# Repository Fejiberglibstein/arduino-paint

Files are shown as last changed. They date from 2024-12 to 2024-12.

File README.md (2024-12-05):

<div align="center">
    <h1>Arduino Paint</h1>
</div>

---

# Project setup

### Buy these

- [Arduino `x1`](https://store-usa.arduino.cc/products/arduino-uno-rev3?gad_source=1)
- [Proximity Sensors `x8`](https://www.adafruit.com/product/4019)
- [LED screen `x1`](https://www.adafruit.com/product/2601?gad_source=1)
- [Matrix Shield `x1`](https://www.adafruit.com/product/2601?gad_source=1)
- [Breadboard `x2`](https://www.adafruit.com/product/239)
- [Male-Female Jumper Wires `x1`](https://store-usa.arduino.cc/products/40-colored-male-female-jumper-wires)
- [Male-Male Jumper Wires `x1`](https://store-usa.arduino.cc/products/40-colored-male-male-jumper-wires)

### Printing
- Print everything found in `models/`
  
  - sensor_frame.stl `x8` (When slicing, orient so the front face is down)
  - back_bracket.stl `x8`
  - lego_base1.stl `x2` (Oriented so the lego fitting faces outwards)
  - lego_base2.stl `x2` (Oriented so the lego fitting faces outwards)

### Constructing the frame
- Construct a lego frame 48x24 studs, (41.2 x 20.6 cm)
  - Add a bridge extending width-wise across the middle to support the platform

- Place a 17.8 x 8.9 cm rectangle oriented vertically in the center of the lego
  frame (see picture below if you're confused)

### Wiring

- Place a sensor in each sensor frame and slot a bracket into the groove at the
  top of the bracket
  - Take each sensor frame and put 2 inside of each sensor base so the pins are face up
    (`./models/lego_base1.stl` and `./models/lego_base2.stl`)
  - Each sensor base will go on the lego frame  (refer to the picture below for details)
    - Each should be 4 studs diagonally backwards from each corner
    - Ensure the mount is angled towards the opposite corner of the frame

- You must wire the proximity sensors all together on 2 breadboards.
    - The breadboards should be placed on opposite ends of the frame
    - Connect 5 volts and GND to the +/- rails
    - The trigger and echo pins of each sensor will be connected to the same
      rail on the breadboard
    - You can follow the diagram found in `./documentation/circuit_design.pdf`

- The matrix shield pins must be soldered before use
    - Either solder wires to the pins to be used for trigger/echo or connect a jumper wire
      to the base of the pin
      
- Insert the pins on the matrix shield into the Arduino pin holes and
  connect the LED matrix to the shield
- Connect all wires on the Arduino to the circuit made on the breadboards, ensuring each sensor gets the correct pin

> <details>
>  <summary><b><code>  SPOILER  </code> Picture of setup</b></summary>
>
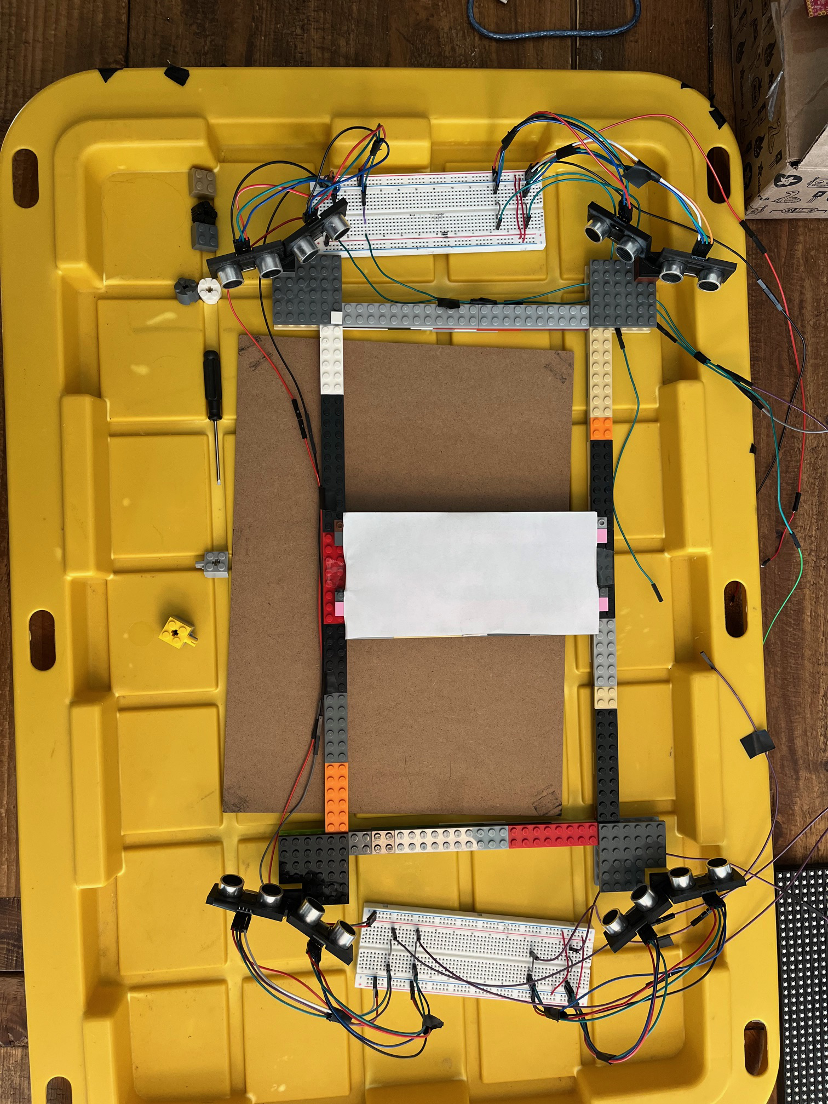
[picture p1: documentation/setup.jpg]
setup image
>  
> </details>

# Using and interacting with the project

### Compiling & Uploading

- Plug the arduino into a computer and compile and upload the sketch by simply
  running `make`, assuming you are on mac/linux and have arduino-cli installed.
    - Prior to this step, disconnect the sensors on pins 0 and 1. Once the sketch is uploaded, connect the wires again

> [!WARNING] 
> ### Using the arduino IDE
> If you are on windows and/or using the Arduino IDE, follow these steps:
> - In the arduino IDE, copy all the `.h` files and their respective `.cpp` files into
>   the arduino library folder into a folder called `math_lib/`.
> - In `arduino-paint.ino`, change the first #include line to the following
> ```diff
> - #include "point_translation.h"
> + #include <point_translation.h>
> ```

- Once it is on, you will be able to trace on the central rectangle and see the
  same trace appear on the LED screen.

- Press the `reset` button on the arduino to clear the screen

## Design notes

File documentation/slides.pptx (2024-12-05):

## Arduino Paint

Austin Thein & Katie Corra

## Project Description

There is a “drawing area” inside the center of a frame. Users can place a long thin object inside this area. By moving the object around, you can “paint” pixels on an LED screen.

## Project Features

- Makes use of proximity sensors in the 4 corners of a rectangle. These proximity sensors are used to triangulate the point being drawn in the drawing area.
- LED screen to display what the user has drawn.

## How it works

We have 2 proximity sensors in each corner of the rectangle. We are using 2 per corner so that the combined angle of effect of the sensors is greater than it would be with just one.
By pinging each sensor individually, we can take the minimum distance from each corner and create a circle for each corner, where the center is the location of the corner relative to the center and the radius is the distance returned by the proximity sensors.
With these 4 circles, we can calculate the point of intersection between all the circles, and then draw that point onto the screen.

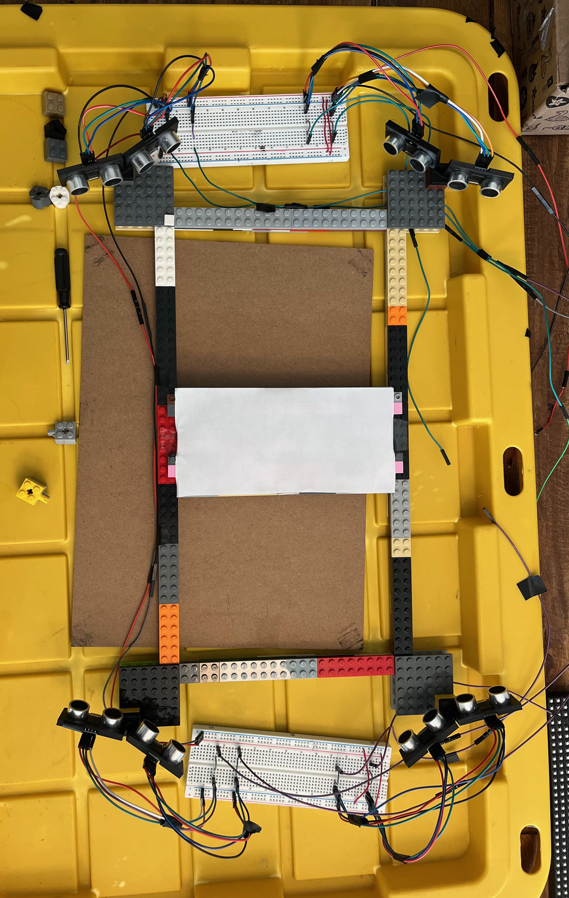
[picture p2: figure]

Final sensor arena

## Challenges we ran into

The sensors were a nightmare. We had to test two different models of sensors (an IR model and ultrasonic sensor model), 17 sensors in total. We had to make sure that each sensor had a accurate reading and had to measure the angle of effect each sensor had.
Each sensor was fine on its own, but after wiring everything together, they would give very inaccurate readings. We “fixed” it by multiplying the distance returned by some magic number, which was a very unsatisfying solution.
Because of our LED screen, we had very few pins to work with. We were forced to use pins 0 and 1, which are the pins the Uno uses for Serial output. Because of this, we were not able to print out any of the distances for each sensor when we were testing with all 8 sensors active. This made testing very annoying.

## Challenges we ran into (part 2)

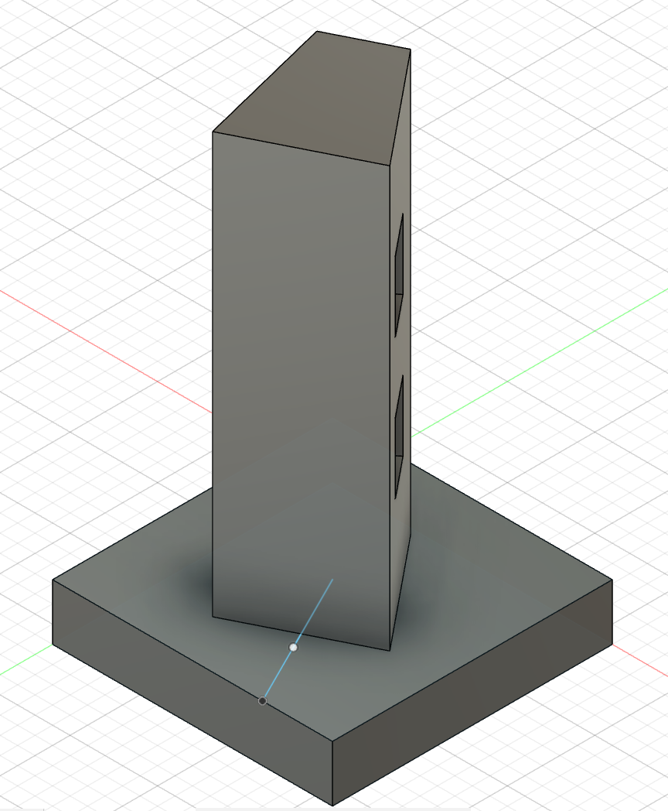
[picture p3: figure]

Initial mount design

We decided to 3D print most of our components, as a lot of them relied on very specific angles to ensure that we could maximize the angle of effect of each corner.
However, our 3D prints changed a lot as our ideas for implementation changed. We had to go through over 5 different iterations of the models before we settled on what we now have.
To print out just one iteration took over 3 hours, so there was a large gap between modeling and the finished print. During one of the prints, we decided midway through on a better model and had to scrap the whole print. All in all, printing everything took over 20 hours.

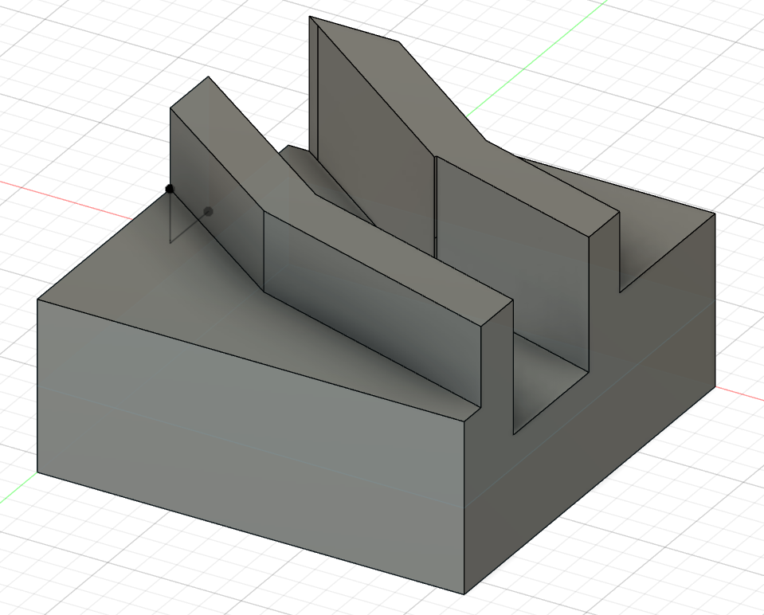
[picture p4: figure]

Final mount design

## Features to add

- We would have liked to add some buttons that allow you to change color/brush size, as well as a button that allows you to erase.
- We would have liked to have a larger area to draw on, since ours is rather small
- Cleaning up wires: putting the breadboards underneath the drawing area so they’re hidden and out of the way.

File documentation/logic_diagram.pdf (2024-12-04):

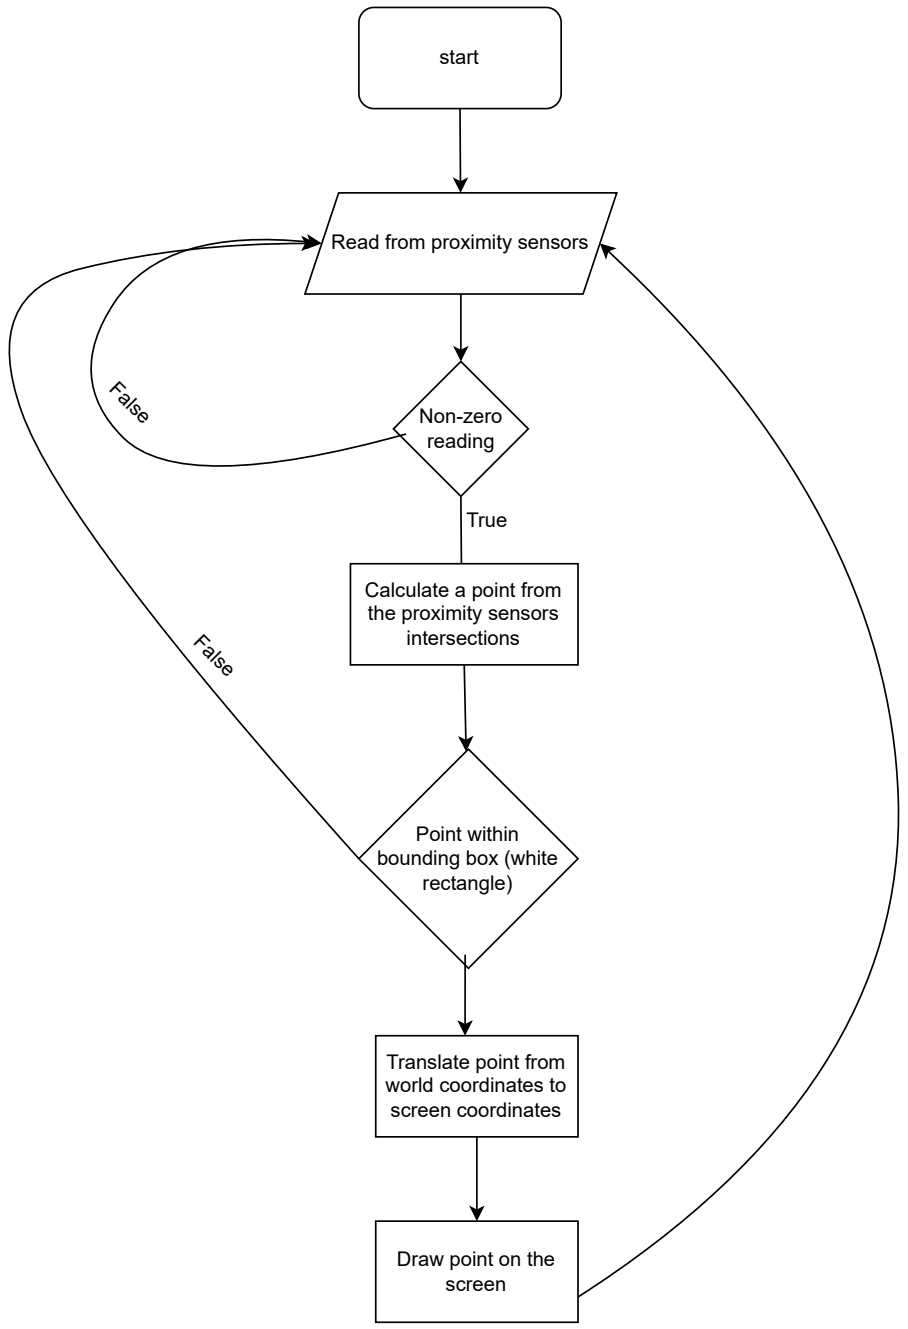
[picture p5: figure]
start; Read from proximity sensors; Non-zero reading; False; Calculate a point from the proximity sensors intersections; Point within bounding box (white rectangle); True; Translate point from world coordinates to screen coordinates; Draw point on the screen

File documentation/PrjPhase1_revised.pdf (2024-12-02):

# CSE 321 Term Project

Authors: Austin Thein, Katie Corra Recipient: Mostafa Mohammed Date: 10/4/2024
Yyyyyyyyyyyyyyyyyyyyy

is sil

Ta

# ble

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
1: U

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
2: S

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
3: D

e

### vic

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
# Project Description

Our term project will be a drawing program. We will use multiple proximity sensors arranged in a rectangular formation as our drawing area and we will have a screen that displays what the user has drawn in real time. When an object, such as a pen or a finger, enters the field, we will determine its location in the real world x z plane and map that real world location to the virtual 2 dimensional canvas that will then be displayed on the screen. There will be a set of buttons that will allow the user to adjust the brush size or the color of the pixel that will be drawn. We did not end up implementing this

# UML

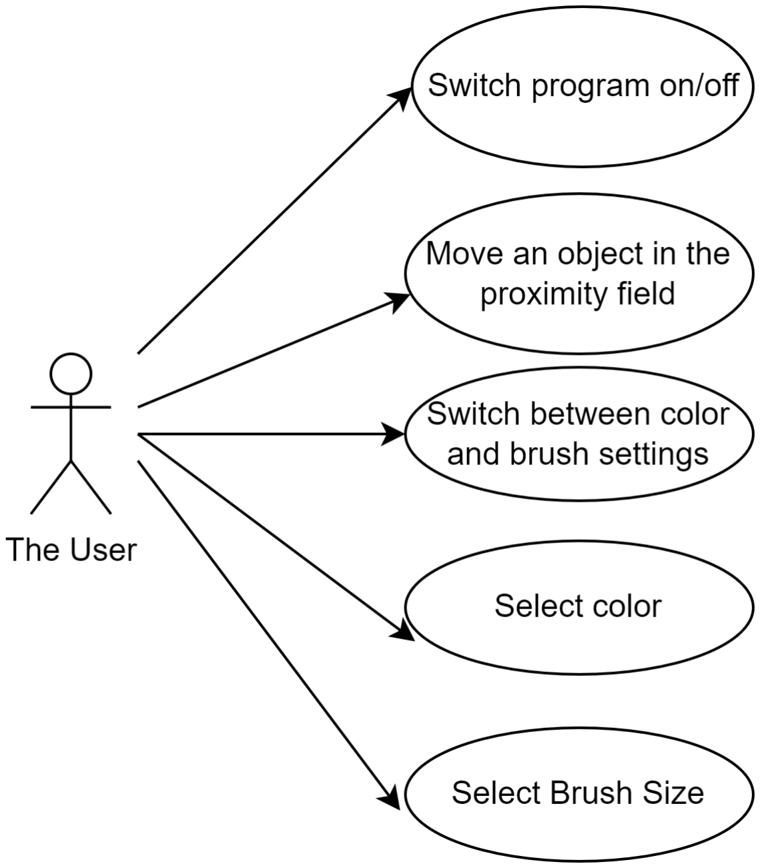
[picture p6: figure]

The UML diagram should not contain switching color/brush, as we did not have time for this

# CRC

### Component 1: User

Responsibilities:

- Turn on the device
- Draw in the proximity area
- Switch color
- Switch size

Collaborators:

- Device

### Component 2: Software

Responsibilities:

- Communication between all components
- Translate location from the proximity area to screen
location.
- Change state (color, brush size) based on what button was pressed

Collaborators:

- Device

### Component 3: Device

Responsibilities:

- Read from the proximity area
- Determine what button was pressed
- Draw to the screen

Collaborators:

- Software
- User

# Architectural Diagram

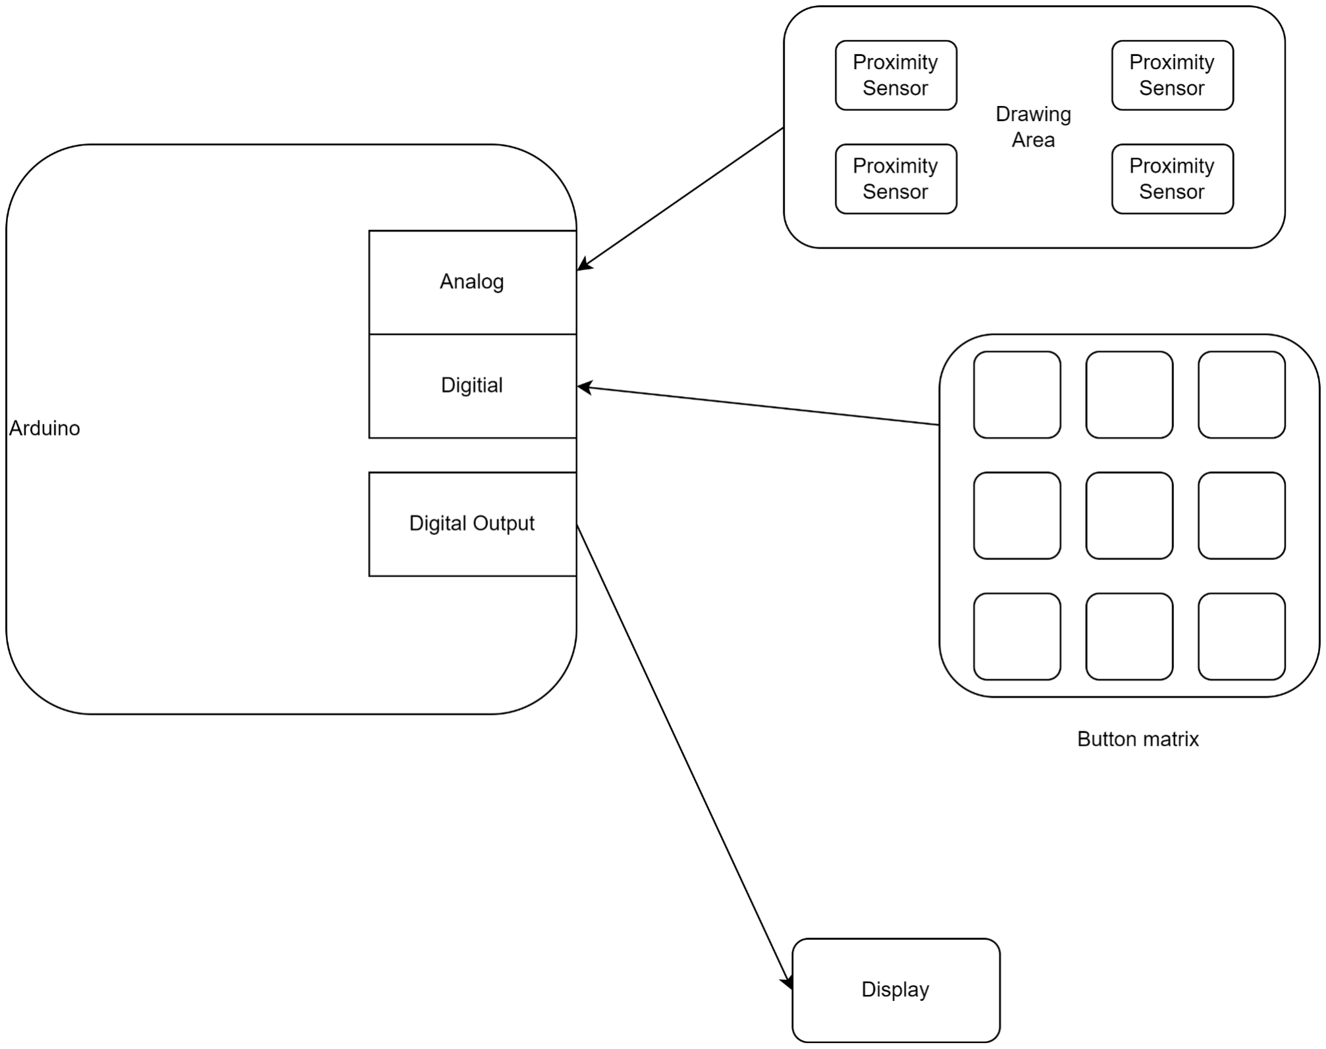
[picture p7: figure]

Button matrix is no longer a part of the architecture

# Flow Chart

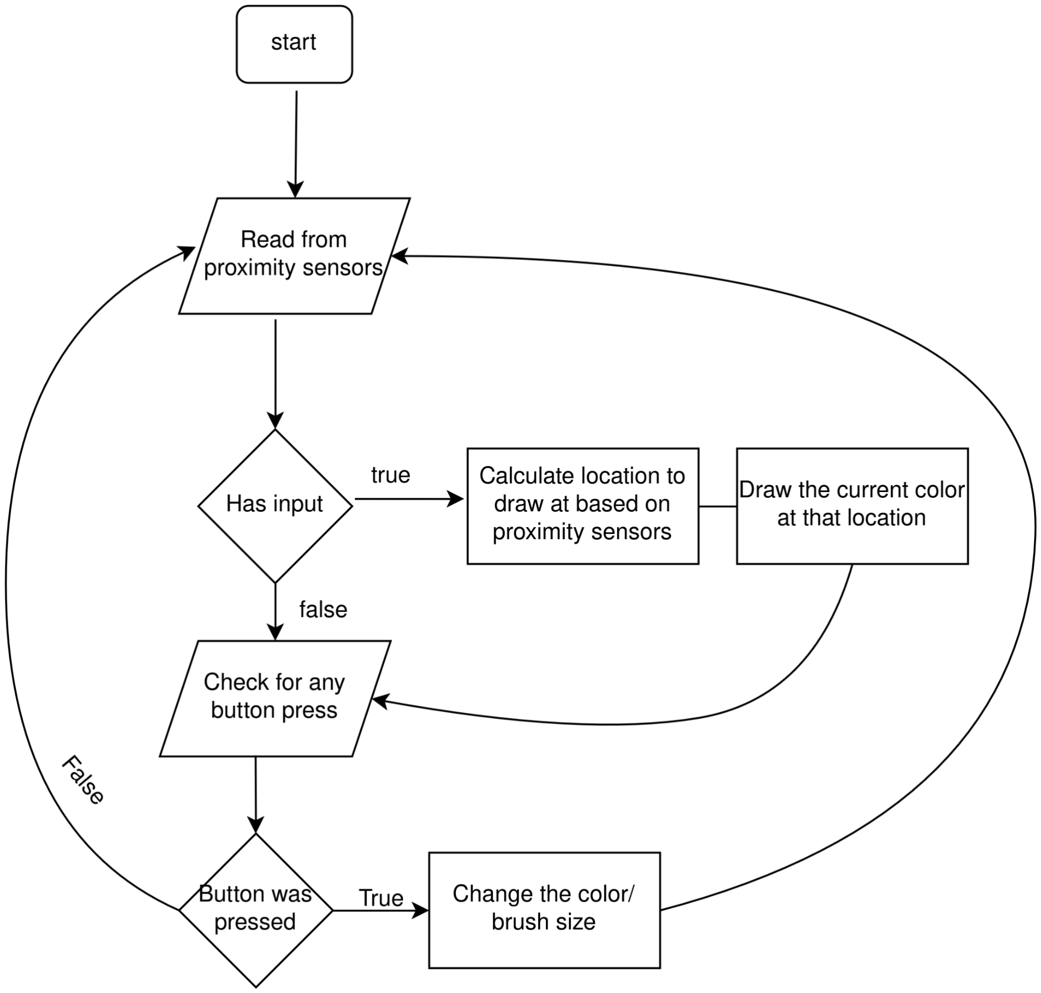
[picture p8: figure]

There should be no “button was pressed” condition anymore in the flow chart

# Components list

Device | Part
Arduino Uno | Arduino Uno Rev3 (https://store-usa.arduino.cc/products/arduino-uno-rev3?gad_source=1)
Proximity sensors | Adafruit VCNL4040 Proximity and Lux Sensor (https://www.adafruit.com/product/4161)
Display | Adafruit RGB Matrix Shield for Arduino (https://www.adafruit.com/product/2601?gad_source=1)
Button Matrix | 16-Button Tactile Keypad Matrix (D72) (https://vetco.net/products/16-button-tactile-keypad-matrix-d72?gad_source=1)

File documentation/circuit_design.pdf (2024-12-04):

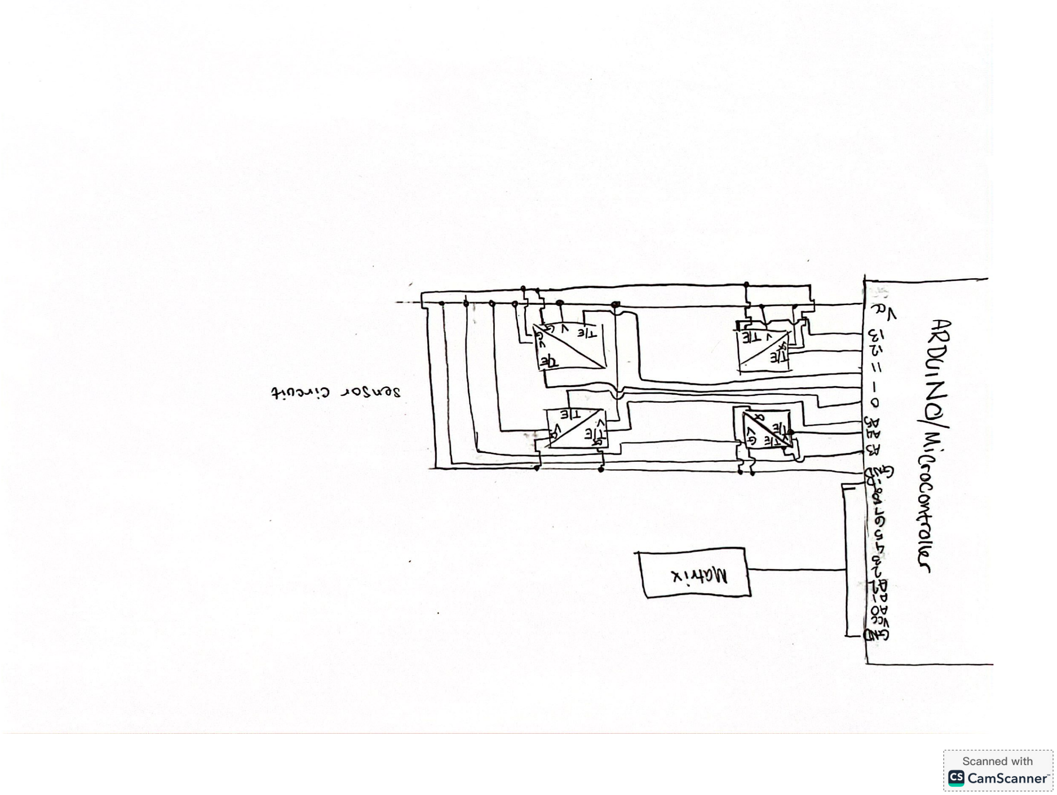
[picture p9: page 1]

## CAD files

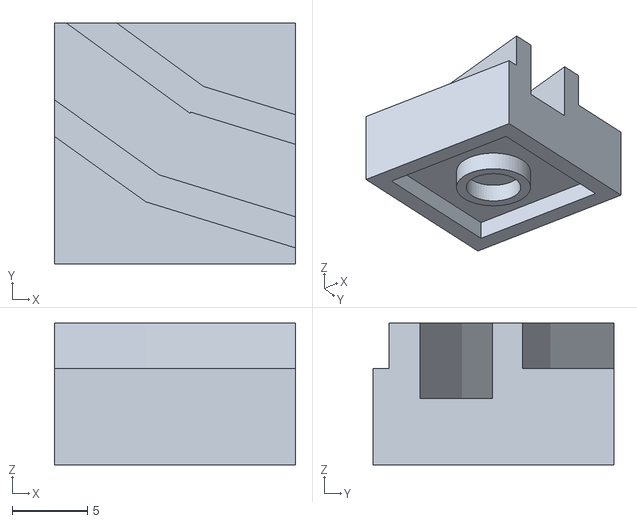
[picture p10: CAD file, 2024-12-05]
models/lego_base2.stl
16.0 x 16.0 x 9.40

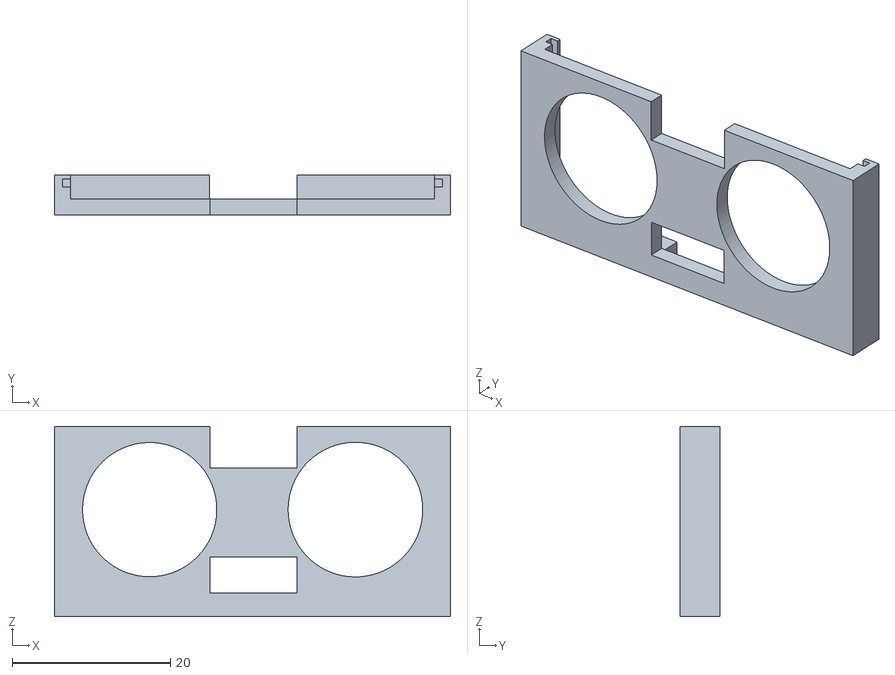
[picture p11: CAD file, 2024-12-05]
models/sensor_frame.stl
50.0 x 5.00 x 24.0

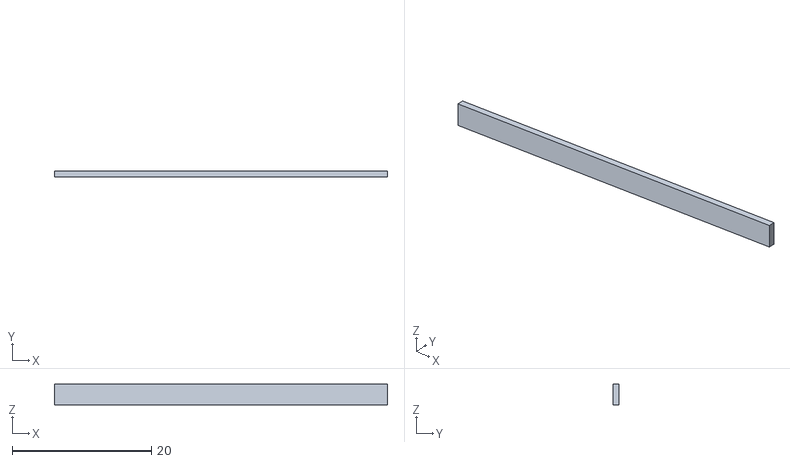
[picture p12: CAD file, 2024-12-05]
models/back_bracket.stl
47.8 x 0.9 x 3.00

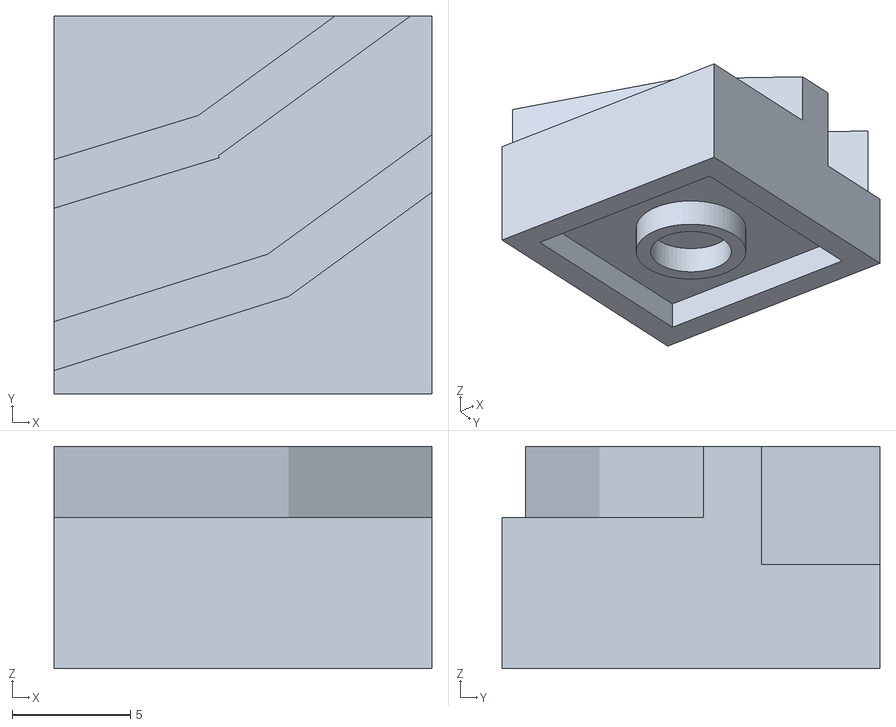
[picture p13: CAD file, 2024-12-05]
models/lego_base1.stl
16.0 x 16.0 x 9.40

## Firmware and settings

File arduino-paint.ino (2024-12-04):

#include "point_translation.h"
#include <RGBmatrixPanel.h>

// IDK how colors work for this, 
#define COLOR matrix.Color333(7, 0, 0)

#define CLK  8
#define OE   9
#define LAT 10
#define A   A0
#define B   A1
#define C   A2

RGBmatrixPanel matrix(A, B, C, CLK, LAT, OE, false);

Corner corners[4] = {
    (Corner){
        .io_pin_left = A3,
        .io_pin_right = A4,

        .x = sensor_coords[0].x,
        .y = sensor_coords[0].y,
    },
    (Corner){
        .io_pin_left = 0, // 0
        .io_pin_right = A5,

        .x = sensor_coords[1].x,
        .y = sensor_coords[1].y,
    },
    (Corner){
        .io_pin_left = 1, // 1
        .io_pin_right = 11,

        .x = sensor_coords[2].x,
        .y = sensor_coords[2].y,
    },
    (Corner){
        .io_pin_left = 12,
        .io_pin_right = 13,

        .x = sensor_coords[3].x,
        .y = sensor_coords[3].y,
    }
};

void setup_screen() {
    matrix.begin();
}


void setup_sensors() {
    // TODO: you will need to do this for all trigpins and echos i think
    // pinMode(trigPin, OUTPUT);
    // pinMode(echo1, INPUT);
    // pinMode(echo2, INPUT);
}

void setup() {
    // Serial.begin(115200);
    setup_screen();
    setup_sensors();
}

int intersections = 0;
int real_intersections = 0;

void binary_display(int k, int loc) {
    for (int i = 15; i >= 0; i --) {
        int r = (k >> i & 1) * 7;
        matrix.drawPixel(loc, i, matrix.Color333(r, r, r));
    }
}

void loop() {
    Circle circles[4] = {0};

    // ping all the corners and get their returned distance into an array of
    // circles
    send_ping(corners, circles);

    // calculate the point from our four circles
    Point p = calculate_point(circles);

    if (p.x != -1 && p.y != -1) {
        // Translate the calculate point's coordinates into from world coordinates
        // to screen coordinates
        p = scale_point(p);
        intersections += 1;
        // binary_display(intersections, 0);

        if (p.x != -1 && p.y != -1) {
            real_intersections += 1;
            // binary_display(real_intersections, 1);
            matrix.drawPixel(p.x, p.y, COLOR);
        }
    }

    // Swapping the x and y here, check the note I left in
    // `point_translation.cpp`


}

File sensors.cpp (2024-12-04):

#include "./sensors.h"
#include <Arduino.h>

#define SENSOR_TO_CENTER 7
#define SENSOR_ANGLE 45

// (SENSOR_TO_CENTER * cos(SENSOR_ANGLE / 2))
const float H = 6.46715673;


Point sensor_coords[4] = {
    (Point){.x = 0,  .y = 0},
    (Point){.x = 20.6, .y = 0},
    (Point){.x = 20.6, .y = 41.2},
    (Point){.x = 0,  .y = 41.2},
};

Point area_coords[4] = {
    // NOTE: the order these are in matters!! do it in the same order please
    // xoxo
    (Point){.x = 2.1854442, .y = 16.542722},
    (Point){.x = 18.414556, .y = 16.542722},
    (Point){.x = 18.414556, .y = 24.657278},
    (Point){.x = 2.1854442, .y = 24.657278},
};


float calc_distance(int pin) {
 //set the pin as output for the trig pin part
    delayMicroseconds(50);
    pinMode(pin, OUTPUT);
    digitalWrite(pin, LOW);
    delayMicroseconds(2);
    // Sets the trigPin on HIGH state for 10 micro seconds
    digitalWrite(pin, HIGH);
    delayMicroseconds(10);
    digitalWrite(pin, LOW);
    //set the pin as input for the echo section
    pinMode(pin, INPUT);
    // Reads the echoPin, returns the sound wave travel time in microseconds
    long duration = pulseIn(pin, HIGH);
    // Calculating the distance
    float distance = duration * 0.0343;

    // pinMode(pin, OUTPUT);
    return distance;
}

float calc_corner_dist(Corner corner) {
    float dist1 = 0;
    if (corner.io_pin_left != -1) {
        dist1 = calc_distance(corner.io_pin_left);
    }
    float dist2 = calc_distance(corner.io_pin_right);
    // just take the smallest of either sensor

    /*Serial.print(dist1);*/
    /*Serial.print("\t");*/
    /*Serial.print(dist2);*/
    /*Serial.println();*/

    if (dist1 == 0 || dist2 == 0) {
        return (dist1 == 0) ? dist2 : dist1;
    }
    /*return (dist1 + dist2) * H * 0.5;*/
    return (dist1 < dist2) ? dist1 : dist2;
}

// Set each to high then calculate the distance
// pulseIn takes an echoPin - each corner has to use a different echo.
// Since it's one corner at a time, borrowing an echo pin from another
// sensor should be fine. May have to do trigger twice per corner in
// case the first times out.
void send_ping(Corner corners[CORNERS], Circle *circles) {
    /*Serial.println("\n\n\n\n\n\n\n");*/
    for (int i = 0; i < 4; i++) {
        circles[i].center = Point{.x = corners[i].x, .y = corners[i].y};
        circles[i].radius = calc_corner_dist(corners[i]);
    }
}

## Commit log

2024-11-11 Hardware testing for sensor configurations and matrix
2024-11-14 Added testing for sensors - 8 pins taken
2024-11-14 Fixed dimension of matrix
    [test_matrix_basic.ino]
2024-12-01 Sensor setup
2024-12-02 Do a bit of fixing
    [proximity.cpp, sensors.cpp]
2024-12-05 Updated slides and models
    [back_bracket.stl, lego_base1.stl, lego_base2.stl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]
